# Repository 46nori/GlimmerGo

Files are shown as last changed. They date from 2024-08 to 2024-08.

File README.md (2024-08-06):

# GlimmerGo
スマートホーム規格である「[Matter](https://csa-iot.org/all-solutions/matter/)」に対応したDIYデバイスを製作してみました。  
特定の誤家庭の課題を解決するために作られたデバイスなので汎用性はありません(笑)。

### 動機
リビングと、子供部屋・仕事部屋間のミスコミニュケーションを解消したい。
- 例1:「こはんできたよ〜」と呼んでも、お父さんは会議中で返事ができずに、お母さんプンスカ！
- 例2: 朝のゴミ当番の子供がいつまでも捨てに行かずに、お母さんプンスカ！

### 要求
- リビングにいるAが、子供部屋や仕事部屋にいるB対し、何種類かの定型メッセージを届けたい。
- Aはメッセージの送信を音声でトリガしたい。またメッセージに対するOK/NGのレスポンスが欲しい。
- しかし、Bはリモート会議や電話をしているため、声によるメッセージは困る。また声によるレスポンスも即座にできないことがある。

## デバイスの概要
2つのContact Sensorと1つのDimmable Lightを内蔵しています。  
中央のFlash LightとLCDパネルがDimmable Lightに、2つの押ボタンスイッチがContact Sensorに割り当てられています。  
Matter ClientからDimmerable LightがONにされると、Flash Lightを点灯させてメッセージの到着を知らせるとともに、Brightnessの値に応じたメッセージをLCDパネルに表示します。  
Contact Sendorは、Matter対応のスマート電球と連携させることで、メッセージへの応答(OK/NG)に使用します。緑のボタンがOKを、赤のボタンがNGです。

システムコントローラには[ESP32-DevKitC-VE ESP32-WROVER-E開発ボード](https://akizukidenshi.com/catalog/g/g115674/)を使用し、ファームウェアはMatter SDKに[esp32-arduino-matter](https://github.com/Yacubane/esp32-arduino-matter/releases)を使ったArduinoのスケッチとして作られています。

### 待機状態
Matter Clientからの通知を待っている状態
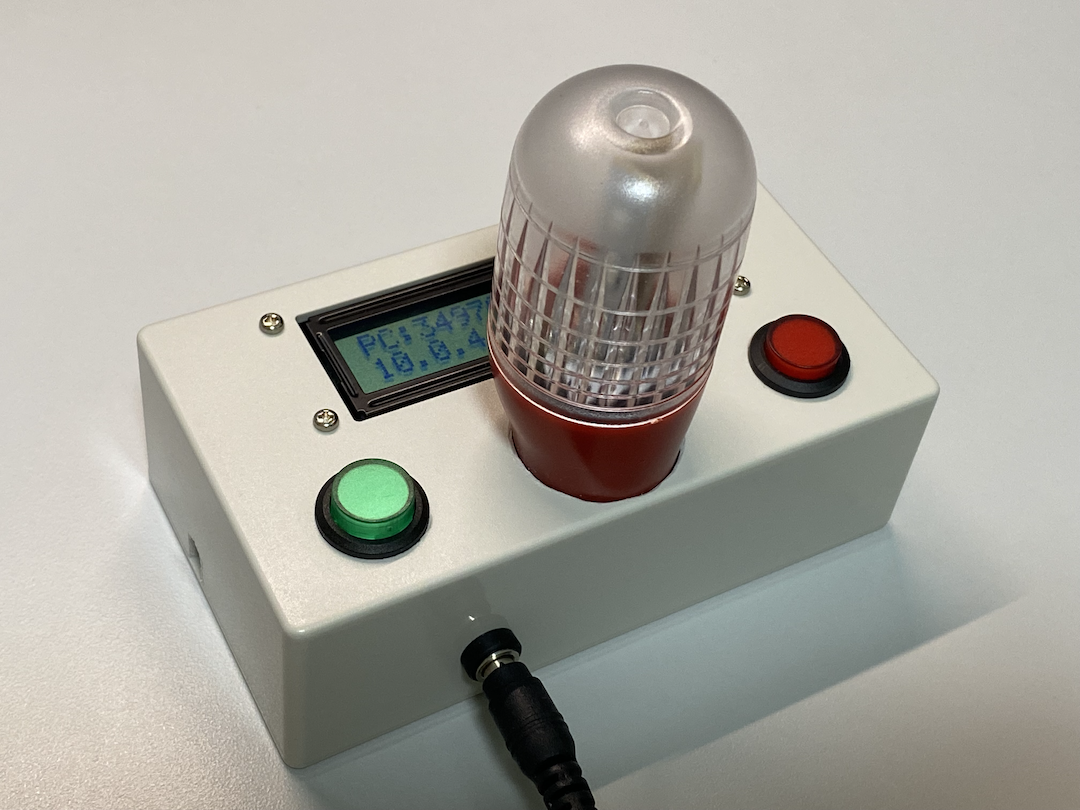
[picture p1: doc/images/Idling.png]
待機時


### 点灯状態
Matter ClientからのMessage通知が届いた状態
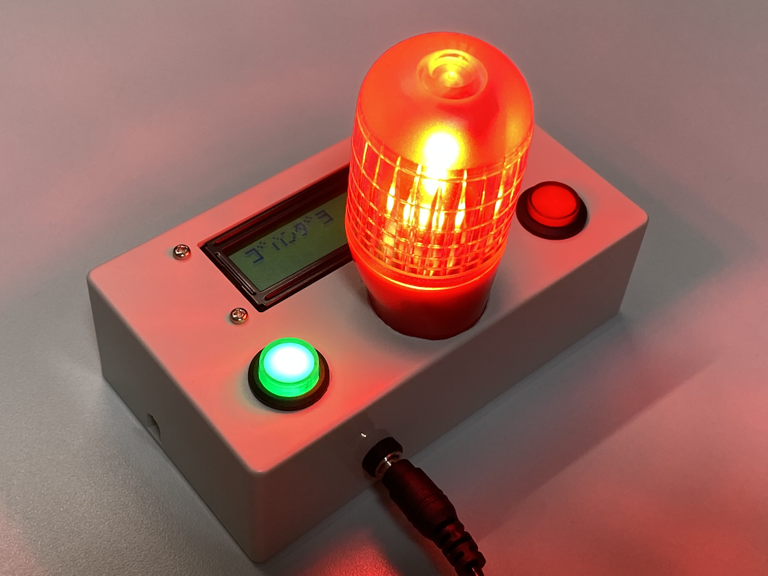
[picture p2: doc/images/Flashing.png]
点灯時


### 動作ビデオ  
Amazon Echoの定型アクションを音声でトリガすることで、こはんができたことをGlimmerGoに通知します。応答として、OKボタン、NGボタンの押下でスマート電球([LDA-8WRGB-VOCE](https://ec.beamtec.co.jp/products/lda-8wrgb-voce))を10秒間点灯させます。  
| OKボタン応答 | NGボタン応答 |
|---|---|
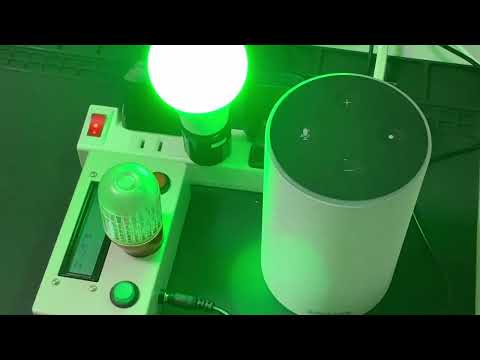
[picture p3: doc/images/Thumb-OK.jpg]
(https://youtu.be/ICXvjUClwUg)
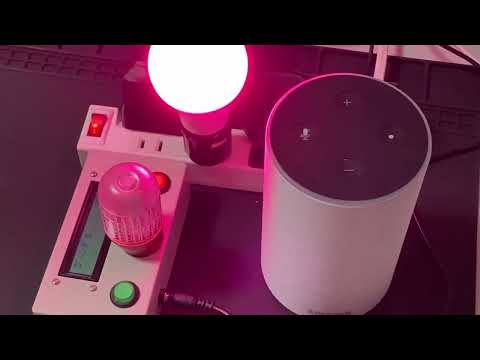
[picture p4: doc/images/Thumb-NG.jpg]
(https://youtu.be/DO7ahDKVq-M)
| | |

(注)Matter Deviceを使用するには、Matterコントローラーが必要です。このビデオではMatter非対応の第一世代Echoを使用していますが、別室に第4世代EchoがありそちらをMatterコントローラーとして使用しています。

## 開発環境
統合環境 : [ArduinoIDE](https://www.arduino.cc/en/software)  
ハードウェア : [ESP32-DevKitC-VE ESP32-WROVER-E開発ボード](https://akizukidenshi.com/catalog/g/g115674/)

ESP32上で`esp32-arduino-matter`を使用するための以下の手順を実行する必要があります。
1. `ArduinoIDE`>`基本設定`
   追加ボードマネージャのURLに以下をセット。
   ```
   https://raw.githubusercontent.com/espressif/arduino-esp32/gh-pages/package_esp32_index.json
   ```
2. `ツール`>`ボードマネージャ`
    `esp32 by Espressif`をインストールする。  
    **バージョンは後述のMatterライブラリのサポートするバージョンにすること。**
3. `ツール`>`ボード`>`esp32`
    `ESP32 Dev Module`を選択
4. C++17対応にする。
    ```Library/Arduino15/packages/esp32/hardware/esp32/2.0.14```を以下のように変更する。(`2.0.14`はインストールした`esp32 by Espressif`に依存する。)
    `-std=gnu++11` → `-std=gnu++17`
5. Matterライブラリのインストールとインストール
   1. GitHubから[esp32-arduino-matter](https://github.com/Yacubane/esp32-arduino-matter/releases)の.zipをダウンロードする。
   2. `スケッチ`>`ライブラリをインクルード`>`.ZIP形式のライブラリをインクルード`
6. ツール設定
   - `ツール`>`Partition scheme:...`>`Minimal SPIFFS (...`
   - この設定を行わないと以下のようなエラーが出る。
     ```
     Library ESP32 Arduino Matter has been declared precompiled:
     Using precompiled library in /Users/xxxxxxx/Documents/Arduino/libraries/ESP32_Arduino_Matter/src/esp32
     最大1310720バイトのフラッシュメモリのうち、スケッチが1692041バイト（129%）を使っています。
     スケッチが大きすぎます。https://support.arduino.cc/hc/en-us/articles/360013825179 には、小さくするコツが書いてあります。
     最大327680バイトのRAMのうち、グローバル変数が100204バイト（30%）を使っていて、ローカル変数で227476バイト使うことができます。
     text section exceeds available space in board

     Compilation error: text section exceeds available space in board
     ```
   - `ツール`>`Flash size:...`>`8MB (64Mb)`
   - `ツール`>`Erase All Flash Before Sketch Upload`>`Enabled`

## ファームウェアのビルドとESP32への焼き込み
1. ArduinoIDEで[GlimmerGo.ino](./Arduino/GlimmerGo/GlimmerGo.ino)を開く。  
   (注) ArduinoIDE起動時にライブラリのアップデートのポップアップが出ても無視すること。
2. [ESP32-DevKitC-VE ESP32-WROVER-E開発ボード](https://akizukidenshi.com/catalog/g/g115674/)とホストPCをUSB接続し、`スケッチ>書き込み`で、スケッチのビルドと書き込みを行う。  
   (橙白黒のケーブルはシリアルモニタ用なので焼き込みには不要。)
   ![](./doc/images/DevEnvironment1.png)
3. 焼き込みに成功すると、LCDパネルにペアリングコードとIPアドレスが表示されます。
   ![](./doc/images/DevEnvironment2.png)

## GlimmerGoの使用方法
- Matterコントローラーを用意する。
  - Amazon Echo以外での動作確認はしていません。Matter対応のEchoについては[こちら](https://www.amazon.co.jp/-/en/b?ie=UTF8&node=16450695051)を参照。
- Matterコントローラーアプリとペアリングを行う。
  - [Amazon Alexaアプリによるデバイスの設定例](./doc/AlexaApp/AlexaApp.md)を参照。

## ドキュメント
- [技術仕様書](./doc/README.md)
- 回路図
   ![](KiCad/GlimmerGo/GlimmerGo.svg)

## License
Apache License Version 2.0

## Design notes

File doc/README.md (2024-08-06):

# 技術仕様書

# 要件
- メッセージの送信側をA, 受信側をBとする。
- Aは、スマートスピーカーを利用してメッセージ送信をトリガする。
- Bは、以下の自作Deviceでメッセージを受信、認識、返答する。
  - メッセージを受信すると、激しめの光を点滅させる。
  - メッセージはLCDパネルに表示する。
  - OK/NGボタン押下でそのメッセージに対する返答を行う。
- 自作DeviceはMatter準拠とする。
  - LED点滅で通知状態(ON/OFF)を知らせるFlash Lightを持つ。
  - 返答用に2つのLED内蔵の物理ボタン、OKボタン(緑)、NGボタン(赤)を持つ。
  - On Off LightとDimmable LightのClusterを実装することで受信メッセージを処理する。
    - Flash LightはOn Off LightのON/OFF状態に同期させる。
    - 定型メッセージはDimmable LightのLevel値で判断し、LCDパネルに表示する。
  - 2つのContact SensorのClusterを実装し、OKボタン、NGボタンを割り当てる。
    - ボタン押下でSensorがON状態にする。一定時間後(10秒)に自動的にOFFに戻す。
  - Deviceのコミッショニングのため、LCDパネルに11桁のPairing Codeを表示する。QR Codeには対応しない。
  - (言うまでもなく)Matter認証には非対応。
- Amazon Alexaを使用する場合
  - AからBへの通知
    - Dimmable LightのLevelでメッセージを指定するような定型アクションを定義する。
    - Aは音声により、この定型アクションをトリガする。
  - BからAへの通知
    - Matter準拠のスマート電球を点灯させることで返答を行う。Aは電球の色でメッセージに対するOK/NGを識別する。
    - Contact Sensorでスマート電球の色設定とON/OFFを行う定型アクションを作成する。OKボタンの押下で緑の点灯、NGボタン押下で赤の点灯を行う。

# ソフトウェア仕様
## Matter Device構造


### On Off Light　Cluster
Matter ClientからON/OFFが指示されたら、Flash Lightを点灯/消灯させる。

### Dimmable Light Cluster
Matter ClientでセットされるBrightness(%)を`dimmer_level`に変換された値として受信する。
受信を検知したら、Flash Lightを点灯させるとともに、`dimmer_level`に対応するMessageをLCD Displayに表示する。

|Brightness (%)|dimmer_level|Message |
|:---:|:---:|---|
|  1 -  19 | 0 -  51 | ｻﾗ ｱﾗｴ  |
| 20 -  39 |  52 - 102 | ｺﾞﾐ ｽﾃﾛ |
| 40 -  60 | 103 - 153 | ｾﾝﾀｸﾓﾉ  |
| 61 -  80 | 154 - 204 | ﾁｮｯﾄｺｲ  |
| 81 - 100 | 205 - 255 | ｺﾞﾊﾝﾀﾞﾖ |

### Contact Sensor Cluster
OKボタンをendpoint_1のContact Sendor 1に、NGボタンをendpoint_2のContact Sendor 2に割り当てる。

## Deive制御
[esp32-arduino-matter](https://github.com/Yacubane/esp32-arduino-matter/tree/master?tab=readme-ov-file)を使用しているため、Device制御のコンテキストは[esp-idf](https://github.com/espressif/esp-idf)のフレームワーク内で動作する。ただしAruduinoのスケッチなので、システム起動時に`setup()`が1回だけ呼び出され、以後`loop()`が定期的に呼び出されるのは、Arduinoのフレームワークと変わりない。

`setup()`では、GPIOやLCD、割り込み等のペリフェラルの初期化後、State Machineを起動する。

`loop()`では、イベントキューからEventオブジェクトを取り出し、`handleEvent()`でState Machineに渡して内部状態を変更する。

Eventオブジェクトは、Matter SDKのコールバック、タイマ発火時、ボタン押下など、非同期にキューにセットされる。

### Eventオブジェクト
EventオブジェクトによりState Machineを駆動する。EventはTypeと1つのパラメータを持つことができる。
| Event Type | Parameter | 用途 |
|---|---|---|
| INIT_COMPLETE | None(0) | システム初期化完了 　　|
| START_FLASH | dimmer_level | Flash Lighの点灯、メッセージのLCD表示要求 |
| STOP_FLASH | None(0) | Flash Lightの消灯 |
| OK_PRESSED | None(0) | OK Button押下 |
| NG_PRESSED | None(0) | NG Button押下 |
| TIMER_EXPIRED | None(0) | Timer発火 |
| IP_CHANGED | None(0) | IP address 変更 |

### State Machine


### Actions
|Action|Parameter||
|---|---|----|
|StartTimer() | N | Timerを起動。N(ms)経過後にイベント`TIMER_EXPIRED`が発生する。 |
|StopTimer() | | Timerを停止する。 |
|SetSwitchOK() | bState | Contact Sensor 1 (endpoint_1)の状態をセットする。trueでON, falseでOFF。 |
|SetSwitchNG() | bState | Contact Sensor 2 (endpoint_2)の状態をセットする。trueでON, falseでOFF。 |
|SetAttr_FlashLight()| bState | Dimmable Light (endpoint_3)の状態をセットする。trueで点灯, falseで消灯。 |
|TurnOn_FlashLight() | | Flash Lightを物理的に点灯させる。 |
|TurnOff_FlashLight()| | Flash Lightを物理的に消灯させる。 |
|SetTwinkleLED() | bOKState, bNGState | OKボタン/NGボタンのLEDの点滅状態を変更する。trueで点滅開始、falseで消灯。 |
|TurnOn_LED() | | ボタンLED、LCDバックライトを点灯させる。 |
|TurnOff_LED() | | ボタンLED、LCDバックライトを消灯させる。 |

## 実装メモ
### Pairing CodeやQR Code URLを取得する方法
- [esp-matter](https://github.com/espressif/esp-matter)の以下のファイルと関数を参照。
    - ファイル: [esp-matter/connectedhomeip/connectedhomeip/src/app/server/OnboardingCodesUtil.cpp](https://github.com/espressif/connectedhomeip/blob/1dc089ce965e6b627b4c4ecd08b0e1882ece6b53/src/app/server/OnboardingCodesUtil.cpp)
    - 関数: `PrintOnboardingCodes()`
      - シリアルのログに、Pairing CodeとQR Code URLが表示する。

- サンプル
  - PrintOnboardingCodes()の呼び出し方法
    ```C++
    PrintOnboardingCodes(chip::RendezvousInformationFlag(chip::RendezvousInformationFlag::kBLE));
    ```

  - Pairing Codeの文字列を取得する方法
    ```C++
      char payloadBuffer[32];
      chip::MutableCharSpan manualPairingCode(payloadBuffer);
      if (GetManualPairingCode(manualPairingCode, chip::RendezvousInformationFlag::kBLE) == CHIP_NO_ERROR) {
        Serial.println(manualPairingCode.data());
        //ChipLogProgress(AppServer, "Manual pairing code: [%s]", manualPairingCode.data());
      } else {
        Serial.println("Pairing Code Error!!");
        //ChipLogError(AppServer, "Getting manual pairing code failed!");
      }
    ```

### cluster_id, attribute_idの定義
- 定義例
  ```C++
  const uint32_t CLUSTER_ID_DIMMABLE_LIGHT   = OnOff::Id;
  const uint32_t ATTRIBUTE_ID_DIMMABLE_LIGHT = OnOff::Attributes::OnOff::Id;
  ```
- ヘッダファイル
  - [esp-matter/connectedhomeip/connectedhomeip/zzz_generated/app-common/app-common/zap-generated/ids/Clusters.h](https://github.com/espressif/connectedhomeip/blob/v1.1-branch/zzz_generated/app-common/app-common/zap-generated/ids/Clusters.h)
  - [esp-matter/connectedhomeip/connectedhomeip/zzz_generated/app-common/app-common/zap-generated/ids/Attributes.h](https://github.com/espressif/connectedhomeip/blob/v1.1-branch/zzz_generated/app-common/app-common/zap-generated/ids/Attributes.h)

## 文献
- Matter
  - [CSA (Connectivity srandards aliance)](https://csa-iot.org/)
  - [Matter仕様書](https://csa-iot.org/developer-resource/specifications-download-request/)
- ESP32 Matter SDK
  - [arduino-esp32](https://github.com/espressif/arduino-esp32)
  - [esp-idef](https://github.com/espressif/esp-idf)
  - [esp-matter](https://github.com/espressif/esp-matter)
  - [connecthomeip](https://github.com/espressif/connectedhomeip)
- 参考記事
  - [【解説】スマートホーム共通規格「Matter」](https://techlabo.ryosan.co.jp/article/24011209_1048.html)
  - [ESP32 (arduino) からAlexaの定型アクションをトリガーしよう](https://qiita.com/wanko_in_lunch/items/68a7be306281aa43fc4b)
  - [ESP32でMatterな接触センサを自作しよう　複数センサ編](https://qiita.com/wanko_in_lunch/items/71316e839f304cc66d6b)
  - [ESP32でMatterな接触センサを自作してAlexa定型アクションを叩こう](https://qiita.com/wanko_in_lunch/items/70ec071083d3c5172880)

# ハードウェア仕様
## 回路図


## 電源
- 外部電源は、9V / 1AのACアダプタ推奨。  
- LCDパネルのバックライト用に、3端子レギュレータで5Vを生成している。熱損失による温度上昇が気になるので、外部電源電圧は9V程度に抑えたい。
- 3.3V系は、三端子DC/DCレギュレーター([BP5293-33](https://akizukidenshi.com/catalog/g/g111187/))で生成。USB電源との衝突防止のため、ショットキーバリア 1S4で分離している。
- Flash Lightの電源は、念の為IN4007で3V以下に降圧させている。

## デバッグ用UART
- ESP32のTX/RX端子をコネクタで接続できるようにし、外部のUSBシリアル変換モジュール[AE-FT234X](https://akizukidenshi.com/catalog/g/g108461/)で変換してホストに接続できるようにしている。
- ArduinoIDEのシリアルモニタで表示ができる。

## パーツ
[BOM](../KiCad/GlimmerGo/BOM.csv)

- コントローラ
  - [ESP32-DevKitC-VE ESP32-WROVER-E開発ボード](https://akizukidenshi.com/catalog/g/g115674/)を使用。
  - Micro USBコネクタでホストに接続して開発を行う。
  - GPIOはたくさんあるように見えるが、制約があり使用できるピンは限られるので注意。([参考情報](https://robot-jp.com/wiki/index.php/Parts:DevBoard:ESP32-DevKitC-32D))
- 押しボタンスイッチ
  - [LED付きプッシュスイッチ R16-503BD](https://www.aitendo.com/product/3599)
  - LEDの詳細が不明なため、電流制限抵抗は現物あわせ。
- LCDパネル
  - [LCDキャラクタディスプレイ 16×2行 3.3V仕様 バックライト付](https://akizukidenshi.com/catalog/g/g114443/)
  - バックライト電源は3.3Vでは不足。5Vを分圧調整している。
  - マニュアルと表示方向が逆？おかげでメッセージの表示が見にくくなってしまった。
- 筐体
  - [プラスチックケース SW-125S(LCD)](https://akizukidenshi.com/catalog/g/g109834/)
  - LCDパネル用の穴加工済みなので便利。が、W:70mm/D:125mm/H:40mmのサイズにパーツを全て押し込めなければならなくなった...。
- Flash Light  
  [エーモンの非常信号灯](https://www.amon.jp/products2/detail.php?product_code=6904)を使用した。3V(単4アルカリ電池2個)でLEDの点滅を行ってくれる。  
  以下のように外殻だけを切断し、電池の接点にコードを接続し、FET 2SK2925でON/OFF制御を行う。  
  |加工前|加工後|
  |-----|-----|
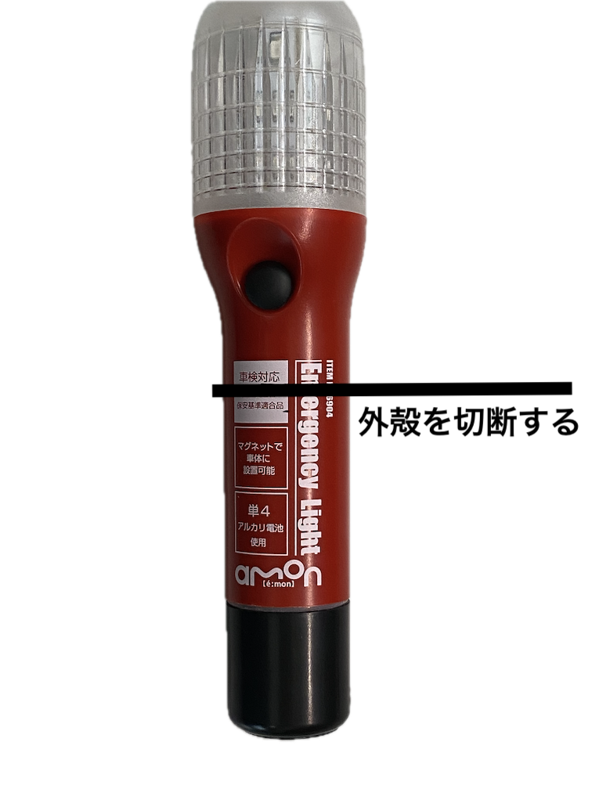
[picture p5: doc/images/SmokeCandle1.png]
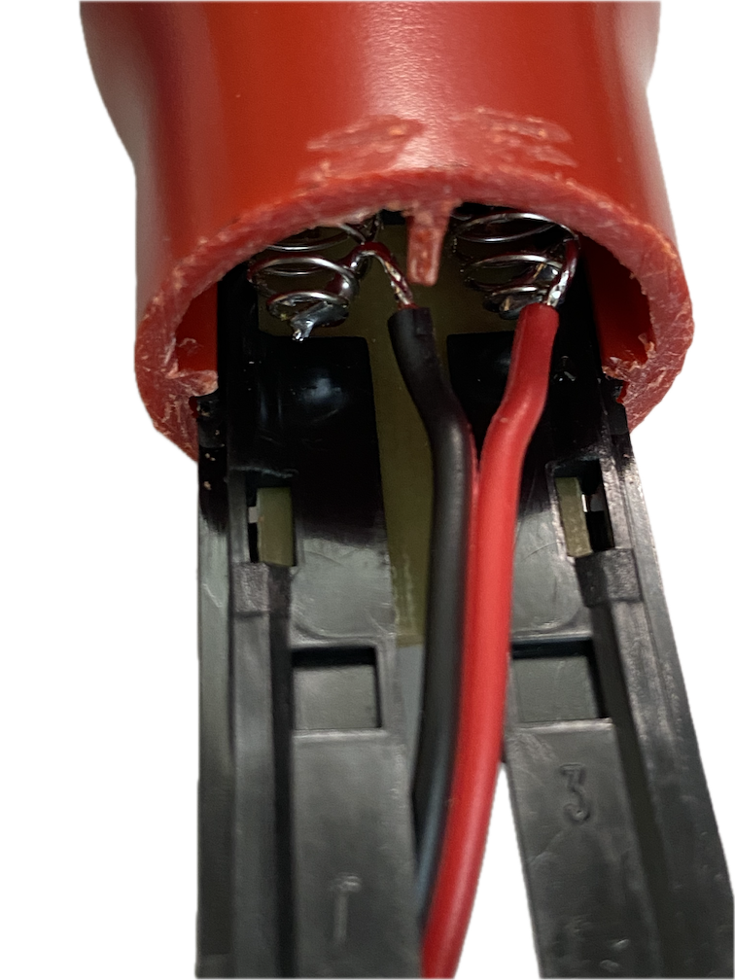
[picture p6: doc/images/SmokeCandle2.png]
  | | |

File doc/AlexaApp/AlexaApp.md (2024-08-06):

# Amazon AlexaアプリによるGlimmerGoの設定例

1. `Amazon Alexa` アプリをスマホ等にインストールし、起動する。
2. `デバイス`メニューを選択し、Matterデバイスの接続を行う。
    |1 |2 |3 |
    |----|----|----|
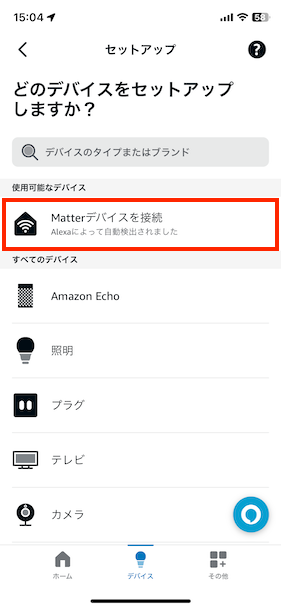
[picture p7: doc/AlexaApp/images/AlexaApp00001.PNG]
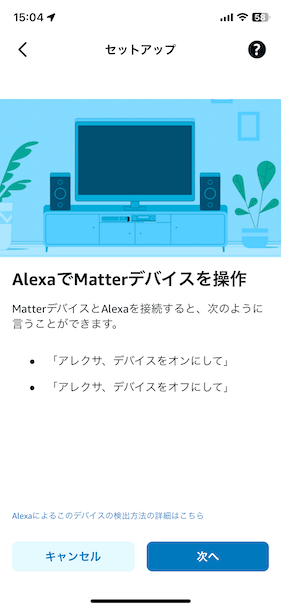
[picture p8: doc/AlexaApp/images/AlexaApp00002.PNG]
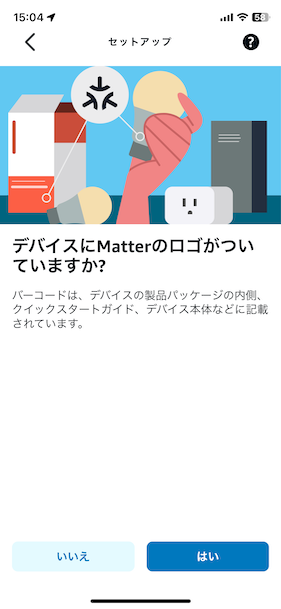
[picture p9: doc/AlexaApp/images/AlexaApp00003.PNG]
    | |  | |
    |4 |5 |6 |
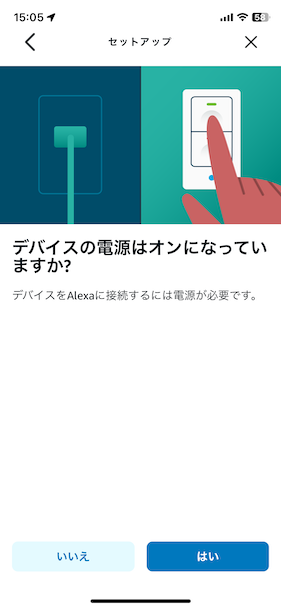
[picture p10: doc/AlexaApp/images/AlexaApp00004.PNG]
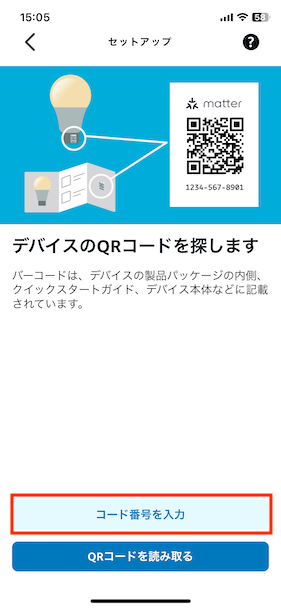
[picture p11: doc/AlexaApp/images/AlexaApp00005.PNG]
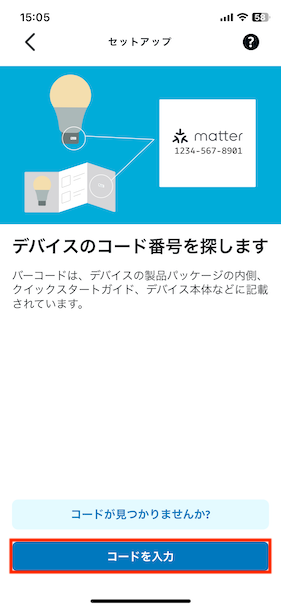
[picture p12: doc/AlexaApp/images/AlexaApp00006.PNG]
    | |  | |
3. LCDパネルに表示されている11桁のペアリングコードを入力する。  
    |1 |2 |3 はいを選択する|
    |----|----|----|
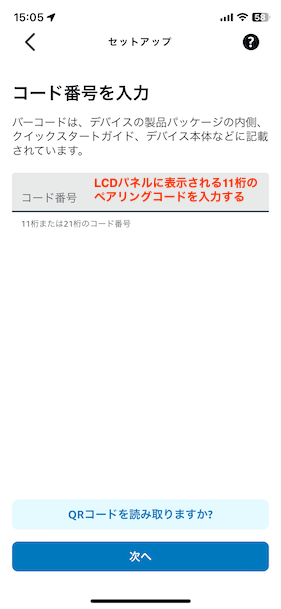
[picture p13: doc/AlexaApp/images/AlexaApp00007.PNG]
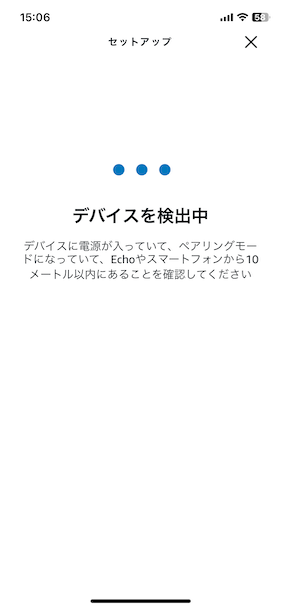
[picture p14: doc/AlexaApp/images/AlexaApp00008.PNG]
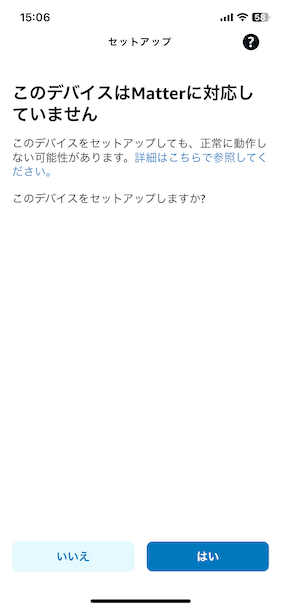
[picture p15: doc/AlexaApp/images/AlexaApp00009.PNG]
    | |  | |
    |4 |5 デバイスが登録できた| |
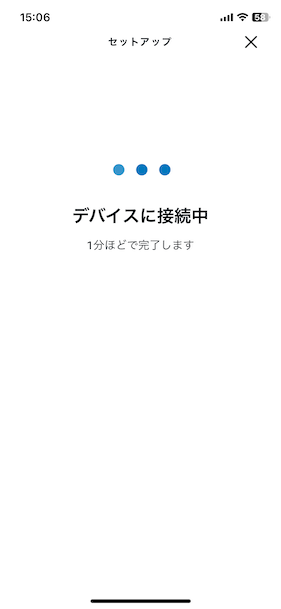
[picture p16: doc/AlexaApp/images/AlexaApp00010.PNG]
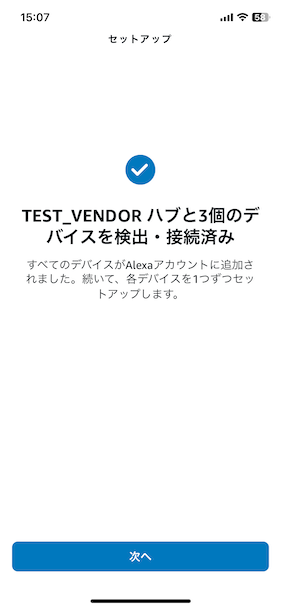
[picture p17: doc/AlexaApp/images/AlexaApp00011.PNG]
    | |  | |
4. Flash Lightの設定
    |1 |2 |3 環境に合わせて設定する|
    |----|----|----|
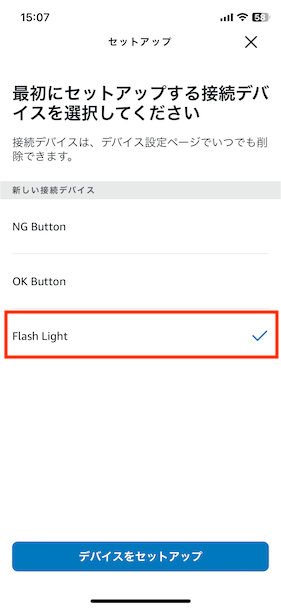
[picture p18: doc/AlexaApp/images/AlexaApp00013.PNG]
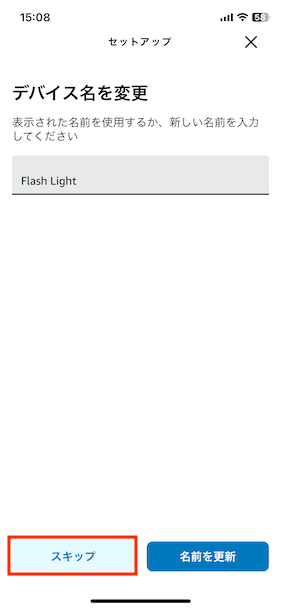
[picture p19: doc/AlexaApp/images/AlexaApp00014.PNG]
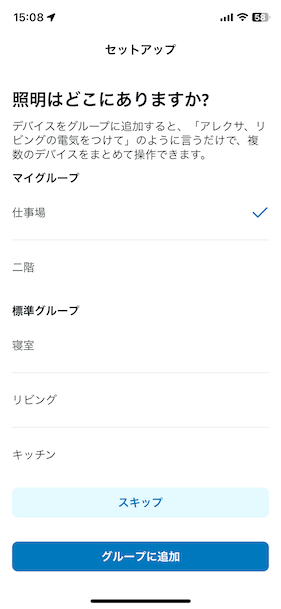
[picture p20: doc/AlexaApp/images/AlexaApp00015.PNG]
    | |  | |
    |4 |5 |  |
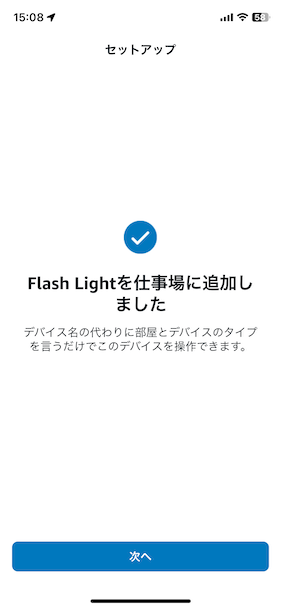
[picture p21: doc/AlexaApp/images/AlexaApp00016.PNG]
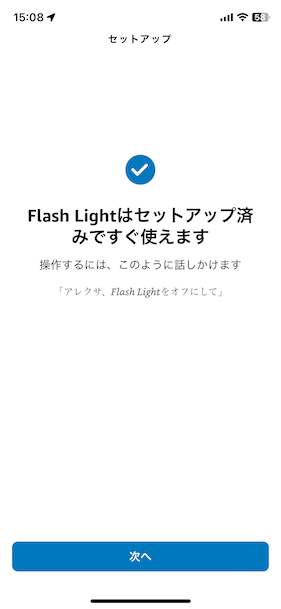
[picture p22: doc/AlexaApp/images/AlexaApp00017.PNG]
    | |  | |
5. 同様にOK Buttonの設定を行う。
6. 同様にNG Buttonの設定を行う。
7. 設定が完了すると、以下が表示される。
    ||
    |----|
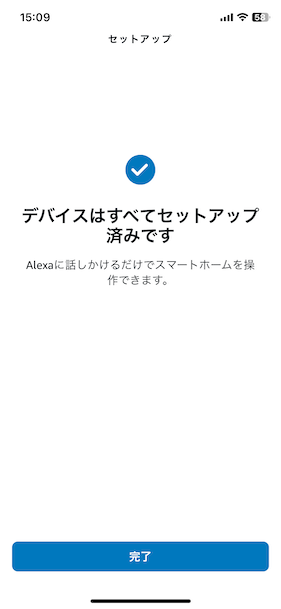
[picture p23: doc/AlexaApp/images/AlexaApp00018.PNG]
    ||
8. `GlimmerGO`を選択すると、Deviceの概要が表示される。
    ||
    |----|
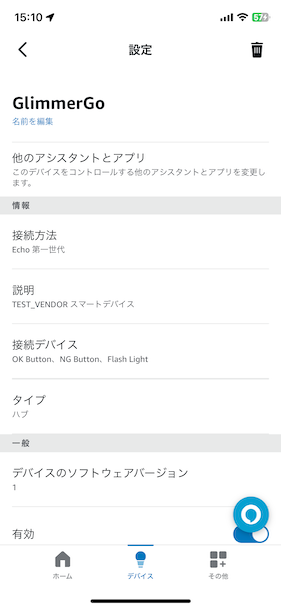
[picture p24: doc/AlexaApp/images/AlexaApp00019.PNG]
    ||
9.  `Flash Light`を選択すると、ON/OFFと明るさの設定が行える。これを使ってFlash Lightの点灯、およびMessageのテストが可能。
    ||
    |----|
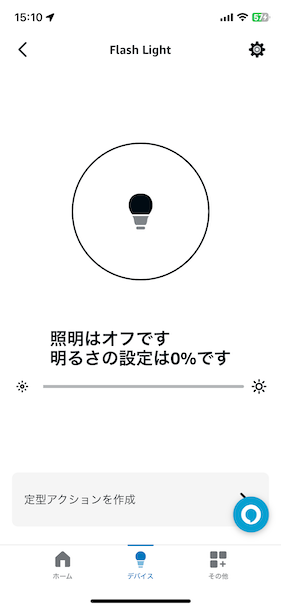
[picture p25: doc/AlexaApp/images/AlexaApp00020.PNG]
    ||
10. OKボタンオン、OKボタンオフ時の定型アクションを作成する。  
    スマート電球(ResponseLight)を**緑**に点灯させる定型アクション、および消灯させる定型アクションはあらかじめ作っておき、ALEXAのアクションに紐づける。
    |1 OKボタンオン|2 |3 |
    |----|----|----|
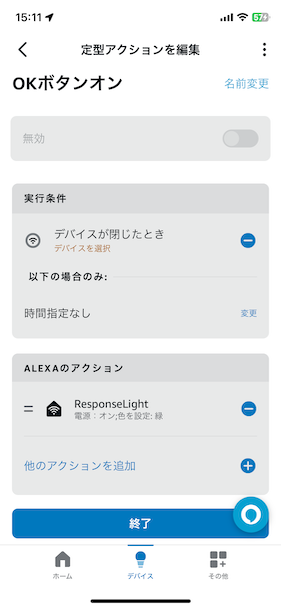
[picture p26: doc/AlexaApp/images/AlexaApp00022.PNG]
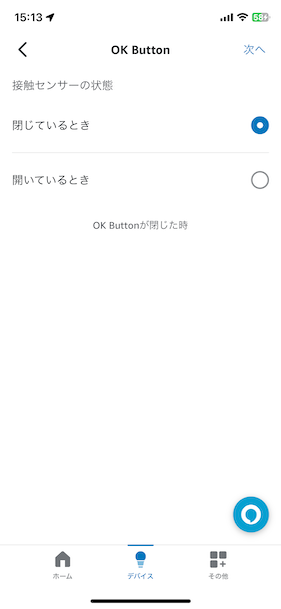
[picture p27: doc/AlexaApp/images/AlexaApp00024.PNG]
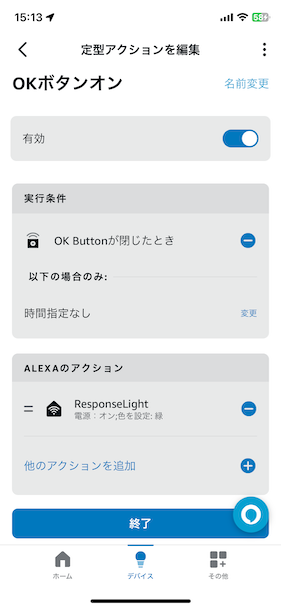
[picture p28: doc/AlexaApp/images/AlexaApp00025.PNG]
    |  | | |
    |1 OKボタンオフ|2 |3 |
    | | `開いている時`で設定 | `ResponseLight`は`電源:オフ`にする|
11. NGボタンオン、NGボタンオフ時も同様の定型アクションを作成する。  
    スマート電球(ResponseLight)を**赤**に点灯させる定型アクション、および消灯させる定型アクションはあらかじめ作っておき、ALEXAのアクションに紐づける。
12. Flsh Light起動用の定型アクションを作成する。  
    これで、「夕食の時間だ」で音声トリガがかかり、Flash Lightが点灯、LCDパネルに「ｺﾞﾊﾝﾀﾞﾖ」が表示されるようになる。
    |1 |2 |3 |
    |----|----|----|
    |  |  | |
    |4 |5 |6 |
    |  |  | |

## スマート電球について
スマート電球は、Beamtecの([LDA-8WRGB-VOCE](https://ec.beamtec.co.jp/products/lda-8wrgb-voce))を使用している。

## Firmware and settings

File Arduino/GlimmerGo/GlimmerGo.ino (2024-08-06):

//
//  GlimmerGo
//
#include <string.h>
#include <queue>
#include <LiquidCrystal.h>
#include "esp_netif.h"
#include "tcpip_adapter.h"

#define ISR_TIMER_TASK 1
#if ISR_TIMER_TASK == 0
#include <freertos/FreeRTOS.h>
#include <freertos/task.h>
#include <freertos/semphr.h>
#endif

#include "Matter.h"
#include <app/server/OnboardingCodesUtil.h>
#include <credentials/examples/DeviceAttestationCredsExample.h>

using namespace chip;
using namespace chip::app::Clusters;
using namespace esp_matter;
using namespace esp_matter::attribute;
using namespace esp_matter::endpoint;

#define DEBUG 1

//============================================================================
// Matter Device
//============================================================================
constexpr char *TAG = "GlimmerGo";    // log

// Device name
constexpr char *DeviceName      = "GlimmerGo";
constexpr char *OK_ButtonName   = "OK Button";
constexpr char *NG_ButtonName   = "NG Button";
constexpr char *FlashLightName  = "Flash Light";

// Cluster and Attribute ID
//  esp-matter/connectedhomeip/connectedhomeip/zzz_generated/app-common/app-common/zap-generated/ids/Clusters.h
//  esp-matter/connectedhomeip/connectedhomeip/zzz_generated/app-common/app-common/zap-generated/ids/Attributes.h
// ContactSensor
constexpr uint32_t CLUSTER_ID_CONTACT_SENSOR   = BooleanState::Id;
constexpr uint32_t ATTRIBUTE_ID_CONTACT_SENSOR = BooleanState::Attributes::StateValue::Id;

// OnOffLight
constexpr uint32_t CLUSTER_ID_ON_OFF_LIGHT     = OnOff::Id;
constexpr uint32_t ATTRIBUTE_ID_ON_OFF_LIGHT   = OnOff::Attributes::OnOff::Id;

// DimmerableLight
constexpr uint32_t CLUSTER_ID_DIMMABLE_LIGHT   = LevelControl::Id;
constexpr uint32_t ATTRIBUTE_ID_DIMMABLE_LIGHT = LevelControl::Attributes::CurrentLevel::Id;

// Endpoint ID
uint16_t endpoint_id_1;     // OK Button
uint16_t endpoint_id_2;     // NG Button
uint16_t endpoint_id_3;     // Signal Light

// Attribute
attribute_t *attribute_1;
attribute_t *attribute_2;         
attribute_t *attribute_3_level;
attribute_t *attribute_3_onoff;

// Device Events
enum class EventType {
  INIT_COMPLETE,
  START_FLASH,
  STOP_FLASH,
  OK_PRESSED,
  NG_PRESSED,
  TIMER_EXPIRED,
  IP_CHANGED
};
struct Event {
    EventType type;
    int param;

    Event(EventType type, int param) : type(type), param(param) {}
};
std::queue<Event> evq;

//
// Initialize Matter device
//
void InitMatterDevice()
{
  //----------------------------------------------------------------------------
  // Setup Cluster and attributes
  //----------------------------------------------------------------------------
  // contact_sensor
  contact_sensor::config_t config_contact_sensor_1;
  config_contact_sensor_1.boolean_state.state_value = false;  // sensor state is open by default
  config_contact_sensor_1.identify.cluster_revision = 4;
  config_contact_sensor_1.identify.identify_time = 0;
  config_contact_sensor_1.identify.identify_type = 0x02;

  // contact_sensor
  contact_sensor::config_t config_contact_sensor_2;
  config_contact_sensor_2.boolean_state.state_value = false;  // sensor state is open by default
  config_contact_sensor_2.identify.cluster_revision = 4;
  config_contact_sensor_2.identify.identify_time = 0;
  config_contact_sensor_2.identify.identify_type = 0x02;

  // on_off_light
  on_off_light::config_t config_on_off_light;
  config_on_off_light.on_off.on_off = false;
  config_on_off_light.on_off.lighting.start_up_on_off = nullptr;

  // dimmable_light
  dimmable_light::config_t config_dimmable_light;
  config_dimmable_light.level_control.current_level = 1;
  config_dimmable_light.level_control.lighting.start_up_current_level = 1;

  // bridge_node
  bridged_node::config_t config_bridged_node;
  config_bridged_node.bridged_device_basic_information.cluster_revision = 1;
  config_bridged_node.bridged_device_basic_information.reachable = true;

  //----------------------------------------------------------------------------
  // Create Root Node
  //----------------------------------------------------------------------------
  node::config_t node_config;
  snprintf(node_config.root_node.basic_information.node_label,
           sizeof(node_config.root_node.basic_information.node_label),
           DeviceName);
  node_t *node = node::create(&node_config, on_attribute_update, on_identification);

  //----------------------------------------------------------------------------
  // Create Endpoint and bind Cluster
  //----------------------------------------------------------------------------
  // Create the root endpoint
  endpoint_t *endpoint_0 = aggregator::create(node, ENDPOINT_FLAG_NONE, NULL);

  // Crete contact_sensor endpoint for OK Button
  endpoint_t *endpoint_1 = bridged_node::create(node, &config_bridged_node, ENDPOINT_FLAG_NONE, NULL);
  contact_sensor::add(endpoint_1, &config_contact_sensor_1);

  // Crete contact_sensor endpoint for NG Button
  endpoint_t *endpoint_2 = bridged_node::create(node, &config_bridged_node, ENDPOINT_FLAG_NONE, NULL);
  contact_sensor::add(endpoint_2, &config_contact_sensor_2);

  // Crete on_off_light/dimmable_light endpoint for Signal Light
  endpoint_t *endpoint_3 = bridged_node::create(node, &config_bridged_node, ENDPOINT_FLAG_NONE, NULL);
  on_off_light::add(endpoint_3, &config_on_off_light);
  dimmable_light::add(endpoint_3, &config_dimmable_light);

  // Set Name to the endpoint
  cluster::bridged_device_basic_information::attribute::create_node_label(cluster::get(endpoint_1, BridgedDeviceBasicInformation::Id),
                                                                          OK_ButtonName,   strlen(OK_ButtonName));
  cluster::bridged_device_basic_information::attribute::create_node_label(cluster::get(endpoint_2, BridgedDeviceBasicInformation::Id),
                                                                          NG_ButtonName,   strlen(NG_ButtonName));
  cluster::bridged_device_basic_information::attribute::create_node_label(cluster::get(endpoint_3, BridgedDeviceBasicInformation::Id),
                                                                          FlashLightName, strlen(FlashLightName));

  // Get endpoint ID
  endpoint_id_1 = endpoint::get_id(endpoint_1);
  endpoint_id_2 = endpoint::get_id(endpoint_2);
  endpoint_id_3 = endpoint::get_id(endpoint_3);

  //----------------------------------------------------------------------------
  // Bind Endpoints to the root node
  //----------------------------------------------------------------------------
  set_parent_endpoint(endpoint_1, endpoint_0);
  set_parent_endpoint(endpoint_2, endpoint_0);
  set_parent_endpoint(endpoint_3, endpoint_0);

  //----------------------------------------------------------------------------
  // Get Attribute of each Endpoint
  //----------------------------------------------------------------------------
  attribute_1       = attribute::get(cluster::get(endpoint_1, CLUSTER_ID_CONTACT_SENSOR), ATTRIBUTE_ID_CONTACT_SENSOR);
  attribute_2       = attribute::get(cluster::get(endpoint_2, CLUSTER_ID_CONTACT_SENSOR), ATTRIBUTE_ID_CONTACT_SENSOR);
  attribute_3_onoff = attribute::get(cluster::get(endpoint_3, CLUSTER_ID_ON_OFF_LIGHT),   ATTRIBUTE_ID_ON_OFF_LIGHT);
  attribute_3_level = attribute::get(cluster::get(endpoint_3, CLUSTER_ID_DIMMABLE_LIGHT), ATTRIBUTE_ID_DIMMABLE_LIGHT);

  //----------------------------------------------------------------------------
  // Start Matter device
  //----------------------------------------------------------------------------
  // Setup DAC (this is good place to also set custom commission data, passcodes etc.)
  esp_matter::set_custom_dac_provider(chip::Credentials::Examples::GetExampleDACProvider());
  esp_matter::start(on_device_event);
}

esp_matter_attr_val_t get_boolean_attribute_value(esp_matter::attribute_t *att_ref)
{
  esp_matter_attr_val_t boolean_value = esp_matter_invalid(NULL);
  attribute::get_val(att_ref, &boolean_value);
  return boolean_value;
}

//----------------------------------------------------------------------------
// Contact sensor
//----------------------------------------------------------------------------
void SetSwitchOK(bool bState)
{
  esp_matter_attr_val_t value = get_boolean_attribute_value(attribute_1);
  value.val.b = bState;
  attribute::update(endpoint_id_1, CLUSTER_ID_CONTACT_SENSOR, ATTRIBUTE_ID_CONTACT_SENSOR, &value);
}

void SetSwitchNG(bool bState)
{
  esp_matter_attr_val_t value = get_boolean_attribute_value(attribute_2);
  value.val.b = bState;
  attribute::update(endpoint_id_2, CLUSTER_ID_CONTACT_SENSOR, ATTRIBUTE_ID_CONTACT_SENSOR, &value);
}

//----------------------------------------------------------------------------
// Dimmer Light
//----------------------------------------------------------------------------
void SetAttr_FlashLight(bool bState)
{
  esp_matter_attr_val_t value = get_boolean_attribute_value(attribute_3_onoff);
  value.val.b = bState;
  attribute::update(endpoint_id_3, CLUSTER_ID_ON_OFF_LIGHT, ATTRIBUTE_ID_ON_OFF_LIGHT, &value);
}

int debug_val_b = 0;
// Update Flash light and notification message on LCD
#define MATTER_BRIGHTNESS 254
#define STANDARD_BRIGHTNESS 255
esp_err_t app_driver_attribute_update(uint16_t endpoint_id, uint32_t cluster_id,
                                      uint32_t attribute_id, esp_matter_attr_val_t *val)
{
  static int dimmer_level = 0;
  if (endpoint_id == endpoint_id_3) {
    if (cluster_id == CLUSTER_ID_ON_OFF_LIGHT) {
      if (attribute_id == ATTRIBUTE_ID_ON_OFF_LIGHT) {
        Serial.print("ATTRIBUTE_ID_ON_OFF_LIGHT=0x");
        Serial.println(attribute_id, HEX);
        Serial.print("val->val.b: ");
        Serial.println(val->val.b);
        // Flash light
        if (val->val.b) {
          evq.emplace(EventType::START_FLASH, dimmer_level);
          debug_val_b = 1;  // debug
        } else {
          evq.emplace(EventType::STOP_FLASH, 0);
          debug_val_b = 0;  // debug
        }
      }
    } else if (cluster_id == CLUSTER_ID_DIMMABLE_LIGHT) {
      if (attribute_id == ATTRIBUTE_ID_DIMMABLE_LIGHT) {
        Serial.print("ATTRIBUTE_ID_DIMMABLE_LIGHT=0x");
        Serial.println(attribute_id, HEX);
        Serial.print("val->val.u8: ");
        Serial.println(val->val.u8);
        dimmer_level = REMAP_TO_RANGE(val->val.u8, MATTER_BRIGHTNESS, STANDARD_BRIGHTNESS);
        if (dimmer_level > 0) {
          evq.emplace(EventType::START_FLASH, dimmer_level);
        }
        debug_val_b = 2;  // debug
      }
    }
  }
  return ESP_OK;
}

//----------------------------------------------------------------------------
// Matter Event Listener
//----------------------------------------------------------------------------
// There is possibility to listen for various device events, related for example
// to setup process. Leaved as empty for simplicity.
static void on_device_event(const ChipDeviceEvent *event, intptr_t arg)
{
    switch (event->Type) {
    case chip::DeviceLayer::DeviceEventType::kInterfaceIpAddressChanged:
        ESP_LOGI(TAG, "Interface IP Address changed");
        evq.emplace(EventType::IP_CHANGED, 0);
        break;
    default:
        break;
    }  
}

static esp_err_t on_identification(identification::callback_type_t type,
                                   uint16_t endpoint_id,
                                   uint8_t  effect_id,
                                   uint8_t  effect_variant,
                                   void *priv_data)
{
  ESP_LOGI(TAG, "Identification callback: type: %u, effect: %u, variant: %u", type, effect_id, effect_variant);
  return ESP_OK;
}

// Listener on attribute update requests.
// In this example, when update is requested, path (endpoint, cluster and attribute) is checked
static esp_err_t on_attribute_update(attribute::callback_type_t type,
                                     uint16_t endpoint_id,
                                     uint32_t cluster_id,
                                     uint32_t attribute_id,
                                     esp_matter_attr_val_t *val,
                                     void *priv_data)
{
#if DEBUG
  // For debug
  Serial.println(">>>>>>>>>>>>>>>>>>>>>>>>>>>>>>>>>>> Begin");
  if (cluster_id == CLUSTER_ID_DIMMABLE_LIGHT) {
    Serial.println("CLUSTER_ID_DIMMABLE_LIGHT");
  }
  if (cluster_id == CLUSTER_ID_CONTACT_SENSOR) {
    Serial.println("CLUSTER_ID_CONTACT_SENSOR");
  }
  if (type == attribute::PRE_UPDATE) {
    Serial.println("attribute::PRE_UPDATE");
  } else {
    Serial.print("attribute::0x");
  Serial.println(type, HEX);
  }
#endif // DEBUG

  esp_err_t err = ESP_OK;

  if (type == PRE_UPDATE) {
    err = app_driver_attribute_update(endpoint_id, cluster_id, attribute_id, val);
  }

#if DEBUG
  Serial.println("<<<<<<<<<<<<<<<<<<<<<<<<<<<<<<<<<<< End");
#endif // DEBUG

  return err;
}

//============================================================================
// LCD
//============================================================================
// Initialize
// PIN settings
//                RS   E  D4  D5  D6  D7
LiquidCrystal lcd(26, 25, 12, 13, 14, 33);
void InitLCD() {
  lcd.begin(16, 2);
  lcd.setCursor(0, 0);
}

//
// Show Notification message
//
void LcdPrint_Message(int value)
{
#if 0
  #define PRINT_LCD_MESSAGE(idx) lcd.print(message_str[idx])
  static constexpr char * const message_str[] = {
    "Wash dishes  ",
    "Dump trash   ",
    "Take laundry ",
    "Come here    ",
    "Dinner       "
  };
#else
  #define PRINT_LCD_MESSAGE(idx) lcd.print(&message_str[idx][0])
  static constexpr char message_str[][8] = {
    {0xbb, 0xd7, 0x20, 0xb1, 0xd7, 0xb4, 0x20, 0},  // ｻﾗ ｱﾗｴ
    {0xba, 0xde, 0xd0, 0x20, 0xbd, 0xc3, 0xdb, 0},  // ｺﾞﾐ ｽﾃﾛ
    {0xbe, 0xdd, 0xc0, 0xb8, 0xd3, 0xc9, 0x20, 0},  // ｾﾝﾀｸﾓﾉ
    {0xc1, 0xae, 0xaf, 0xc4, 0xba, 0xb2, 0x20, 0},  // ﾁｮｯﾄｺｲ
    {0xba, 0xde, 0xca, 0xdd, 0xc0, 0xde, 0xd6, 0}   // ｺﾞﾊﾝﾀﾞﾖ
  };
#endif

  lcd.clear();
  if (value < 51) {
    PRINT_LCD_MESSAGE(0);
  } else if (value < 102) {
    PRINT_LCD_MESSAGE(1);
  } else if (value < 153) {
    PRINT_LCD_MESSAGE(2);
  } else if (value < 204) {
    PRINT_LCD_MESSAGE(3);
  } else {
    PRINT_LCD_MESSAGE(4);
  }

  // debug
  char val_str[4];
  snprintf(val_str, sizeof(val_str), "%03d", value);
  lcd.setCursor(13,0);
  lcd.print(val_str);
}

//
//  Show pairing code
//
void LcdPrint_PairingCode()
{
  char payloadBuffer[32];
  // Print codes needed to setup Matter device
  PrintOnboardingCodes(chip::RendezvousInformationFlags(chip::RendezvousInformationFlag::kBLE));

  chip::MutableCharSpan manualPairingCode(payloadBuffer);
  if (GetManualPairingCode(manualPairingCode, chip::RendezvousInformationFlag::kBLE) == CHIP_NO_ERROR) {
    Serial.println(manualPairingCode.data());
    lcd.clear();
    lcd.print("PC:");
    lcd.print(manualPairingCode.data());
    ChipLogProgress(AppServer, "Manual pairing code: [%s]", manualPairingCode.data());
  } else {
    Serial.println("Pairing Code Error!!");
    ChipLogError(AppServer, "Getting manual pairing code failed!");
  }
}

//
//  Show IP address
//
void LcdPrint_IPaddress()
{
  esp_netif_ip_info_t ip_info;
  esp_netif_get_ip_info(esp_netif_get_handle_from_ifkey("WIFI_STA_DEF"), &ip_info);
  lcd.setCursor(0,1);
  lcd.print(ip4addr_ntoa((const ip4_addr_t *)&ip_info.ip));
}

//============================================================================
// GPIO
//============================================================================
// PIN assignment
#define LCDBK_LIGHT   (32)
#define FLASH_LIGHT   (4)
#define OK_BUTTON     (22)
#define OK_BUTTON_LED (23)
#define NG_BUTTON     (18)
#define NG_BUTTON_LED (19)

void InitGPIO()
{
  pinMode(OK_BUTTON, INPUT_PULLUP);
  pinMode(NG_BUTTON, INPUT_PULLUP);
  pinMode(LCDBK_LIGHT, OUTPUT);
  pinMode(FLASH_LIGHT, OUTPUT);
  pinMode(OK_BUTTON_LED, OUTPUT);
  pinMode(NG_BUTTON_LED, OUTPUT);
  TurnOff_LED();
  TurnOff_FlashLight();
}

void TurnOn_FlashLight()
{
  digitalWrite(FLASH_LIGHT, HIGH);
}

void TurnOff_FlashLight()
{
  digitalWrite(FLASH_LIGHT, LOW);
}

void TurnOn_LED()
{
  digitalWrite(LCDBK_LIGHT, HIGH);
  digitalWrite(OK_BUTTON_LED, LOW);
  digitalWrite(NG_BUTTON_LED, LOW);
}

void TurnOff_LED()
{
  digitalWrite(LCDBK_LIGHT, LOW);
  digitalWrite(OK_BUTTON_LED, HIGH);
  digitalWrite(NG_BUTTON_LED, HIGH);
}

bool bOKEnable = false;
bool bNGEnable = false;
void SetTwinkleLED(bool bOKState, bool bNGState)
{
  bOKEnable = bOKState;
  bNGEnable = bNGState;
}

void TwinkleLED_ISR(long counter)
{
  if (bOKEnable) {
    digitalWrite(OK_BUTTON_LED,  (counter % 1000 < 500) ? LOW: HIGH);
  }
  if (bNGEnable) {
    digitalWrite(NG_BUTTON_LED,  (counter % 1000 < 500) ? LOW: HIGH);
  }
}

bool IsButtonPressed(int button)
{
  return digitalRead(button) == LOW;
}

//============================================================================
// Timer
//============================================================================
volatile unsigned long interruptCounter = 0L;
volatile unsigned long response_timer = 0L;

portMUX_TYPE timerMux = portMUX_INITIALIZER_UNLOCKED;

#if ISR_TIMER_TASK
hw_timer_t * timer = NULL;
void IRAM_ATTR onTimer()
{
	portENTER_CRITICAL_ISR(&timerMux);
	interruptCounter++;

  // Check response_timer
  if (response_timer > 0) {
    if (response_timer == 1) {
      evq.emplace(EventType::TIMER_EXPIRED, 0);
    }
    response_timer -= 1;
  }
	portEXIT_CRITICAL_ISR(&timerMux);

  TwinkleLED_ISR(interruptCounter);
}

#define TICK (1000L)
void InitTimer()
{
	timer = timerBegin(0, 80, true);        // prescaler 80MHz / 80
	timerAttachInterrupt(timer, &onTimer, true);
	timerAlarmWrite(timer, TICK, true);     // 1ms
	timerAlarmEnable(timer);
}
#else  // not ISR_TIMER_TASK
void TimerTask(void *pvParameter)
{
  while (1)
  {
    interruptCounter++;

    // Check response_timer
    if (response_timer > 0) {
      if (response_timer == 1) {
        evq.emplace(EventType::TIMER_EXPIRED, 0);
      }
      response_timer -= 1;
    }

    TwinkleLED_ISR(interruptCounter);
    vTaskDelay(pdMS_TO_TICKS(1000));      // wait 1s
  }
}
#endif

void StartTimer(unsigned long n)
{
	portENTER_CRITICAL(&timerMux);
  response_timer = n;                     // n ms
	portEXIT_CRITICAL(&timerMux);
}

void CancelTimer()
{
	portENTER_CRITICAL(&timerMux);
  response_timer = 0L;
	portEXIT_CRITICAL(&timerMux);
}

//============================================================================
// Device State Controller
//============================================================================
class Initializing;
class Idling;
class Flashing;
class RespondingOK;
class RespondingNG;

//
// State base class
//
class State {
public:
  virtual ~State() {}
  virtual void entry() {}
  virtual void exit() {}
  virtual void handle(const Event& event) = 0;
  virtual State* nextState(const Event& event) = 0;
  int get_state() { return m_state; }
protected:
  int m_state;
};

//
// Concrete States
//
class Initializing : public State {
public:
  void entry() {
    m_state = 0;
    SetTwinkleLED(true, true);
    InitMatterDevice();
    SetAttr_FlashLight(false);
    delay(3000);      // wait 3 sec to be stable
    SetTwinkleLED(false, false);
  }
  void handle(const Event& event) override {
  }
  State* nextState(const Event& event) override;
};

class Idling : public State {
public:
  void entry() {
    m_state = 1;
    SetTwinkleLED(false, false);
    TurnOff_LED();
    LcdPrint_PairingCode();
    LcdPrint_IPaddress();
  }
  void handle(const Event& event) override {
  }
  State* nextState(const Event& event) override;
};

class Flashing : public State {
public:
  void entry() {
    m_state = 2;
    TurnOn_FlashLight();
    TurnOn_LED();
  }
  void exit() {
    TurnOff_FlashLight();
    TurnOff_LED();
  }
  void handle(const Event& event) override {
  }
  State* nextState(const Event& event) override;
};

class RespondingOK : public State {
public:
  void entry() {
    m_state = 3;
  }
  void handle(const Event& event) override {
  }
  State* nextState(const Event& event) override;
};

class RespondingNG : public State {
public:
  void entry() {
    m_state = 4;
  }
  void handle(const Event& event) override {
  }
  State* nextState(const Event& event) override;
};

//
// State instances
//
Initializing  initializingState;
Idling        idlingState;
Flashing      flashingState;
RespondingOK  respondingNG_State;
RespondingNG  respondingOK_State;

//
// Transitions
//
State* Initializing::nextState(const Event& event) {
  if (event.type == EventType::INIT_COMPLETE) {
    SetSwitchOK(false);
    SetSwitchNG(false);
    return &idlingState;
  }
  return this;
}

State* Idling::nextState(const Event& event) {
  if (event.type == EventType::START_FLASH) {
    LcdPrint_Message(event.param);
    return &flashingState;
  }
  if (event.type == EventType::IP_CHANGED) {
    return this;
  }
  return this;
}

State* Flashing::nextState(const Event& event) {
  if (event.type == EventType::OK_PRESSED) {
    SetSwitchOK(true);
    SetAttr_FlashLight(false);
    SetTwinkleLED(true, false);
    StartTimer(10000);    // 10s
    return &respondingOK_State;
  }
  if (event.type == EventType::NG_PRESSED) {
    SetSwitchNG(true);
    SetAttr_FlashLight(false);
    SetTwinkleLED(false, true);
    StartTimer(10000);    // 10s
    return &respondingNG_State;
  }
  if (event.type == EventType::STOP_FLASH) {
    return &idlingState;
  }
  if (event.type == EventType::START_FLASH) {
    LcdPrint_Message(event.param);
    return this;
  }
  return this;
}
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
void loop()
{
  if (!evq.empty()) {
    sm->handleEvent(evq.front());
    evq.pop();
  }
  lcd.setCursor(14, 1);
  lcd.print(debug_val_b, HEX);        // debug: show flash light status
  lcd.setCursor(15, 1);
  lcd.print(sm->get_state(), HEX);    // debug: show current state

  // Check button event
  if (IsButtonPressed(OK_BUTTON)) {
    evq.emplace(EventType::OK_PRESSED, OK_BUTTON);
  } else if (IsButtonPressed(NG_BUTTON)) {
    evq.emplace(EventType::NG_PRESSED, NG_BUTTON);
  }
}
